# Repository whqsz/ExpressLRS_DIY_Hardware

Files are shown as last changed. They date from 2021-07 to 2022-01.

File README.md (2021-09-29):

# DIY ExpressLRS E19 E28 ESP32 TX And RX
开源固件访问http://github.com/ExpressLRS/ExpressLRS

view elrs view

接收机
----------------------------------------------------------

接收编译固件名[env:DIY_900_RX_ESP8285_SX127x_via_UART]

915M接收板子尺寸15mm×16mm×4.5mm厚

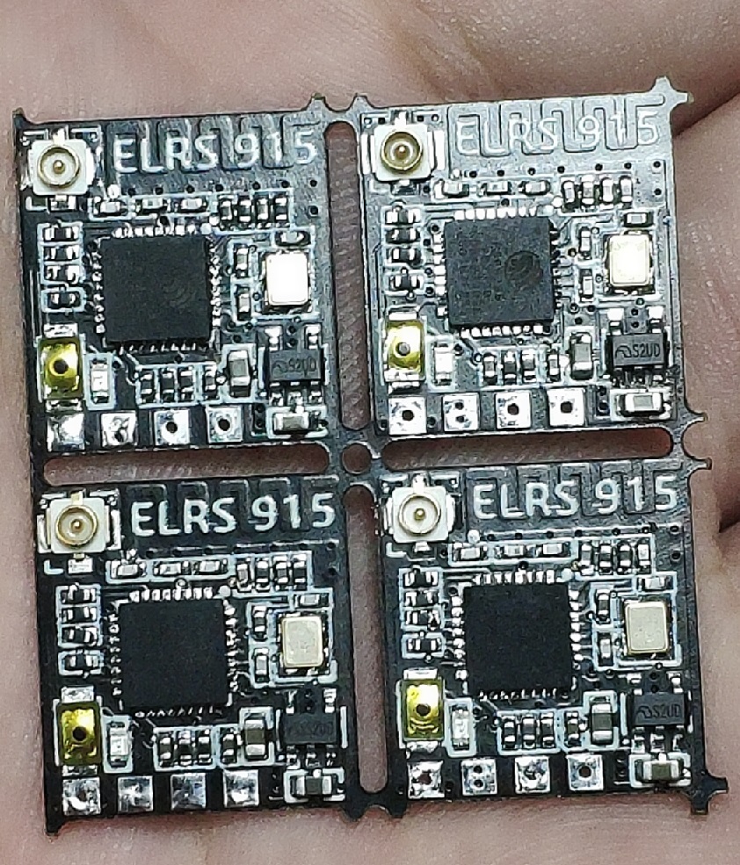
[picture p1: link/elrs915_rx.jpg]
view elrs view


发射机
----------------------------------------------------------

发射编译固件名[env:DIY_900_TX_ESP32_SX127x_E19_via_UART]

发射板targets.h文件定义在65行修改

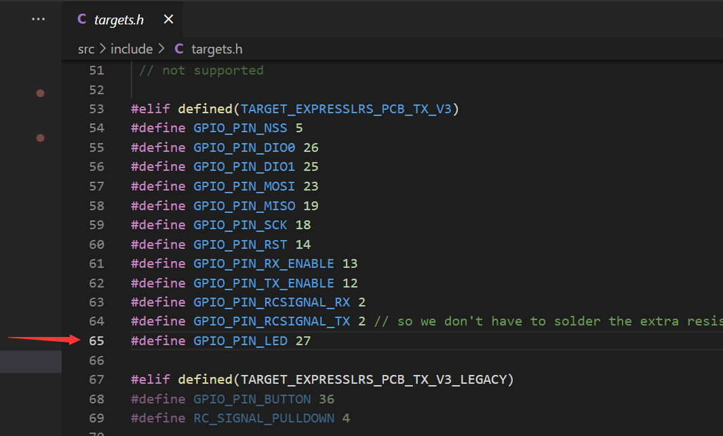
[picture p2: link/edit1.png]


加风扇IO定义

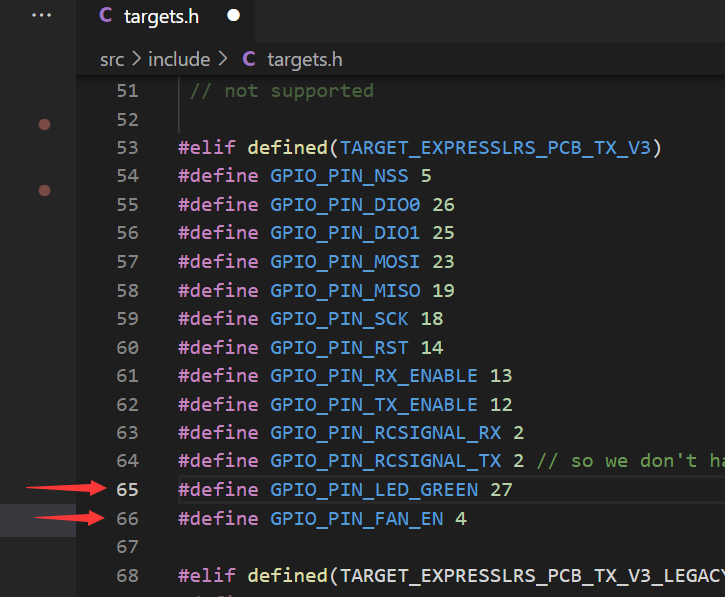
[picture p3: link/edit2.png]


 飞友自制实物
 
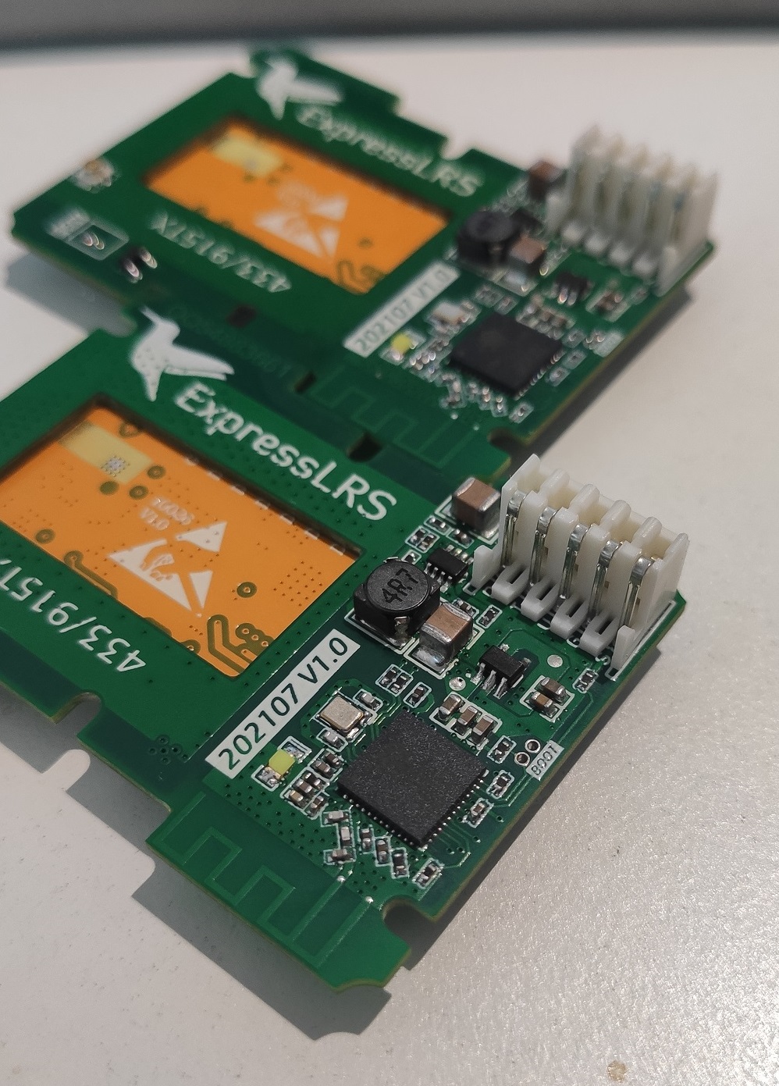
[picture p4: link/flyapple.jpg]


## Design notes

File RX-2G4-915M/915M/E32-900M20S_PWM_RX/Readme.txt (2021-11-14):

基于ExpressLRS 2.0官方源码库引脚定义整理电路图，射频模块选用亿佰特定制型号E32-900M20S
此型号模块内部同样采用SX1276方案，跟常用方案唯一区别就是把天线控制信号调整为由外部单片机端来控制，
所以要在原固件引脚定义下增加两行TXEN跟RXEN定义来驱动射频天线发收状态。
此版本硬件未加入电池电压检测回传，后续要等固件功能加入再做硬件定义。
排针PWM引脚复用功能，同样可以兼容DIY_900_RX CRSF协议固件

PWM1	-- BOOT0下载对GND短接
PWM2	-- TX串口下载 CRSF通讯
PWM3	-- RX串口下载 CRSF通讯
PWM4	--
PWM5	--
PWM6	--

-------------------------------------------------------------------------------------------------------------------------
ExpressLRS 2.0固件添加收发控制定义：
工程文件路径为（ExpressLRS-2.0.0-RC1\src\include\target\DIY_900_RX_PWMP.h）
文本编辑DIY_900_RX_PWMP.h文件，文本结尾追加两行定义：

#define GPIO_PIN_RX_ENABLE      7
#define GPIO_PIN_TX_ENABLE      6

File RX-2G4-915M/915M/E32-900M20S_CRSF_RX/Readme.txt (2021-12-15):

基于ExpressLRS 2.0官方源码库引脚定义整理电路图，射频模块选用亿佰特定制型号E32-900M20S
此型号模块内部同样采用SX1276方案，跟常用方案唯一区别就是把天线控制信号调整为由外部单片机端来控制，
所以要在原固件引脚定义下增加两行TXEN跟RXEN定义来驱动射频天线发收状态。

-------------------------------------------------------------------------------------------------------------------------
ExpressLRS 2.0固件添加收发控制定义：
工程文件路径为（ExpressLRS-2.0.0-RC1\src\include\target\DIY_900_RX_ESP8285_SX127x）
文本编辑DIY_900_RX_ESP8285_SX127x文件

文本结尾追加一行定义：
#define GPIO_PIN_TX_ENABLE      9
#define GPIO_PIN_RX_ENABLE      10

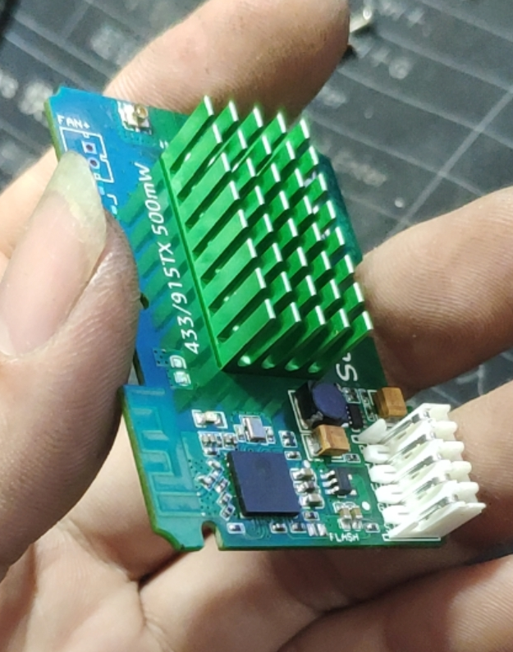
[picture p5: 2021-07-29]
TX/433-915TX/实物.png

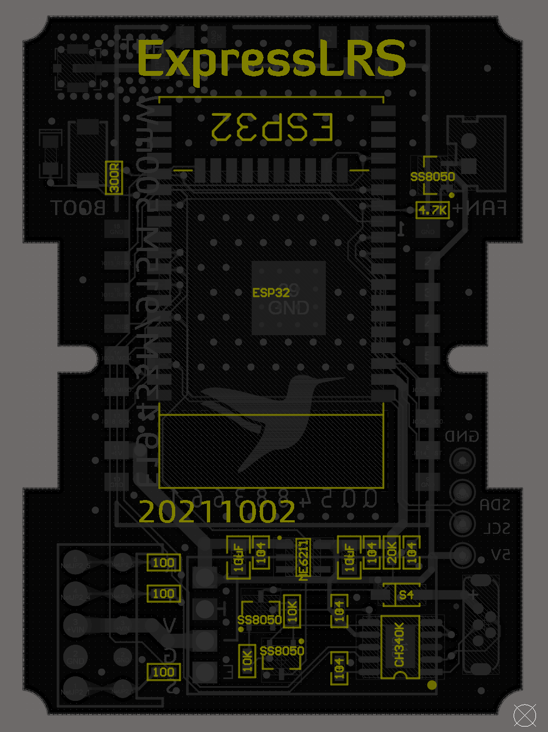
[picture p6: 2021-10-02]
TX/E19_915M_ESP32_FULL_MODULE/焊接点位图.png

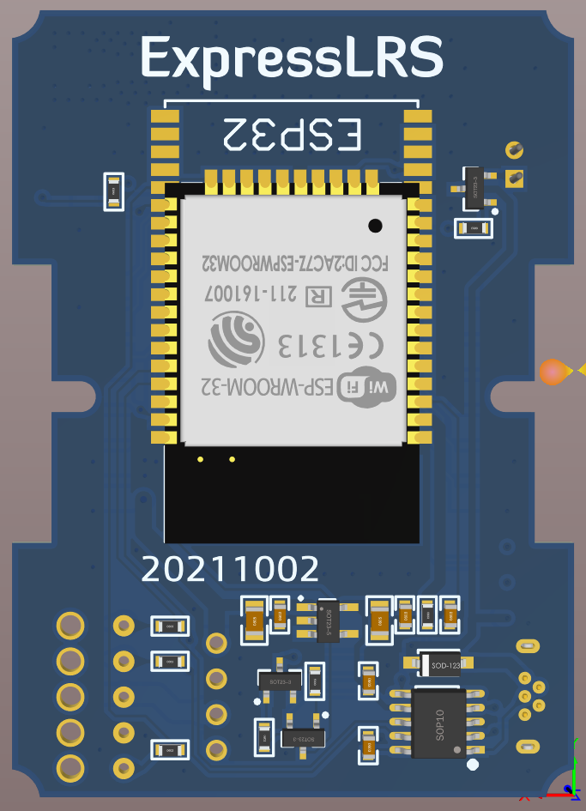
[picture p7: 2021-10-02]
TX/E19_915M_ESP32_FULL_MODULE/3D后.png

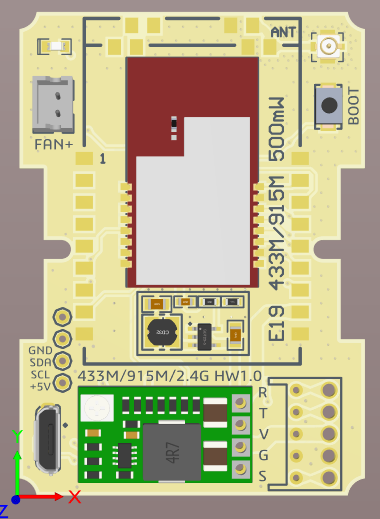
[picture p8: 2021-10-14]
TX/E19_915M_ESP32_2IN1_TX/3D正面.png

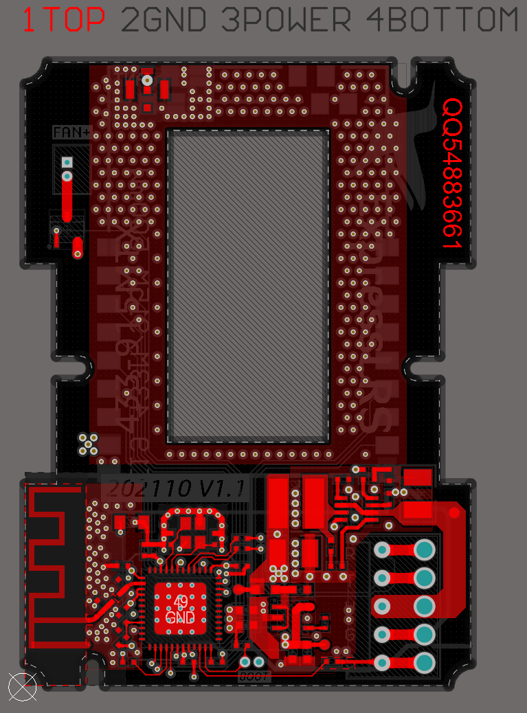
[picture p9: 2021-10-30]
TX/433-915TX/TOP_LAYER.png

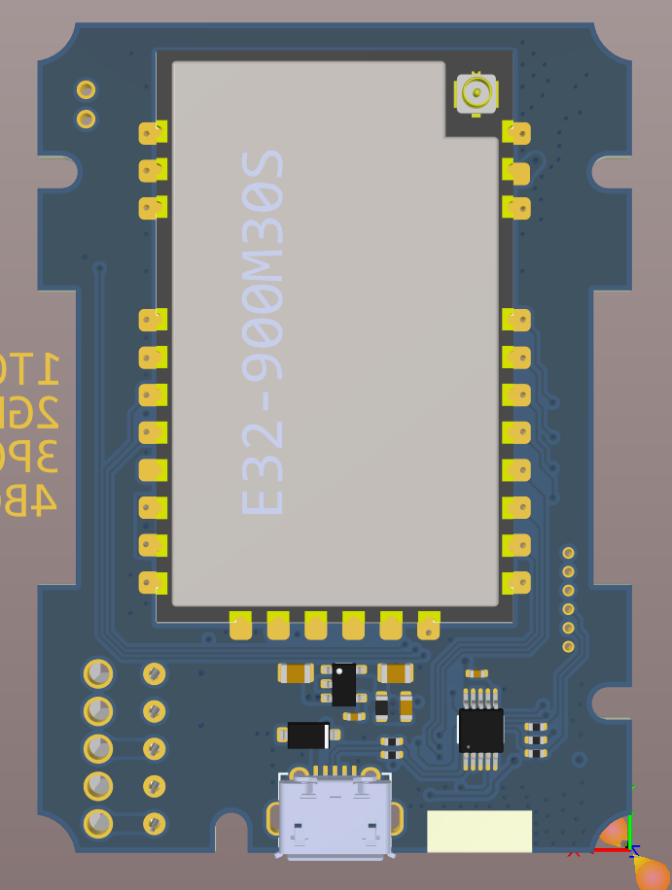
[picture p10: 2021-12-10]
TX/E32_900M30S_TX/3D背面.png

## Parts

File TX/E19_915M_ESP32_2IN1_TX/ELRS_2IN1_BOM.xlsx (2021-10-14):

Comment | Description | Designator | Footprint | LibRef | Quantity
100nF | 无极性贴片电容, Capacitor | C1, C3, C4, C6, C9, C10 | C 0603_L | C, Cap | 6
10uF | 无极性贴片电容, Capacitor | C2, C5, C7, C8 | C 0805_L | C, Cap | 4
S4 | 肖特基二极管 | D1 | SOD123 | SS14 | 1
HDR-1X3 | 3P接插件 | JP1 | IPEX | Header 3 | 1
HDR-1X4 | 4P接插件 | JP2 | J-LINK | Header 4 | 1
HDR-1X2 | 2P接插件 | JP3 | PH2.0-2 | Header 2 | 1
HDR-1X5 | 5P接插件 | JP4 | B2541BW-5P | Header 5 | 1
HDR-1X4 | 4P接插件 | JP5 | MP2315-MODULE-SMT | Header 4 | 1
2.2uH | 小功率贴片电感 | L1 | CD32 | L | 1
RED_LED | 贴片LED | LED1 | LED0805TB | LED-SMD | 1
SS8050 | 高频放大-NPN型 | Q1, Q2, Q3 | SOT23-3L | 8050-SMD | 3
20K | 贴片电阻 | R1 | R 0603_L | R | 1
470R | 贴片电阻 | R2 | R 0603_L | R | 1
100R | 贴片电阻 | R3, R5, R6 | R 0603_L | R | 3
1K | 贴片电阻 | R4 | R 0603_L | R | 1
45K | 贴片电阻 | R7 | R 0603_L | R | 1
10K | 贴片电阻 | R8, R9, R10 | R 0603_L | R | 3
FLASH | 侧按直插6x6轻触开关 | SW1 | KEY-K2 | TSW DIP-6x6_V | 1
E19-433/915M30S | 433/915射频模块 | U1 | E19_2IN1 | LORA-SX1276M | 1
ESP32 | ESP32模块 | U2 | ESP32 | ESP32 | 1
STI3408B_1A | 3.3V降压IC | U3 | SOT23-5L | STI3408B_1A | 1
ME6211 | 3.3V降压压LDO | U4 | SOT23-5M | ME6211 | 1
LORA-E28-2G4M | 2.4G射频模块 | U5 | E28-2G4M2XS | LORA-E28-2G4M | 1
CH340K | USB到TTL芯片 | U6 | CH340K | CH340K | 1
USB-5P | 微型USB母座 | USB1 | USB-micro_C | USB-5P | 1

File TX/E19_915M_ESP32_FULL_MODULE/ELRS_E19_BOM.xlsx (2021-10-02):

Comment | Description | Designator | Footprint | LibRef | Quantity
104 | 无极性贴片电容 | C1, C3, C5, C6, C7 | C 0603_L | C | 5
10uF | 无极性贴片电容 | C2, C4 | C 0805_L | C | 2
S4 | 肖特基二极管 | D1 | SOD123 | SS14 | 1
HDR-1X2 | 2P接插件 | JP1 | PH2.0-2 | Header 2 | 1
HDR-1X5 | 5P接插件 | JP2 | B2541BW-5P | Header 5 | 1
HDR-1X3 | 3P接插件 | JP3 | IPEX | Header 3 | 1
HDR-1X4 | 4P接插件 | JP4 | MP2315-MODULE-SMT | Header 4 | 1
HDR-1X4 | 4P接插件 | JP5 | J-LINK | Header 4 | 1
RED_LED | 贴片LED | LED1 | LED0805TB | LED-SMD | 1
SS8050 | 高频放大-NPN型 | Q1, Q2, Q3 | SOT23-3L | 8050-SMD | 3
470R | 贴片电阻 | R1 | R 0603_L | R | 1
20K | 贴片电阻 | R2 | R 0603_L | R | 1
4.7K | 贴片电阻 | R3 | R 0603_L | R | 1
100 | 贴片电阻 | R4, R5, R6 | R 0603_L | R | 3
10K | 贴片电阻 | R7, R8 | R 0603_L | R | 2
FLASH | 侧按直插6x6轻触开关 | SW1 | KEY-K2 | TSW DIP-6x6_V | 1
ESP32 | 乐鑫ESP32模块 | U1 | ESP32 | ESP32 | 1
ME6211 | 3.3V LDO | U2 | SOT23-5M | ME6211 | 1
E19-433/915M30S | 亿佰特915模块 | U3 | E19_2IN1 | LORA-SX1276M | 1
CH340K | USB转串口芯片 | U4 | CH340K | CH340K | 1
USB-5P | 微型USB母座 | USB1 | USB-micro_C | USB-5P | 1

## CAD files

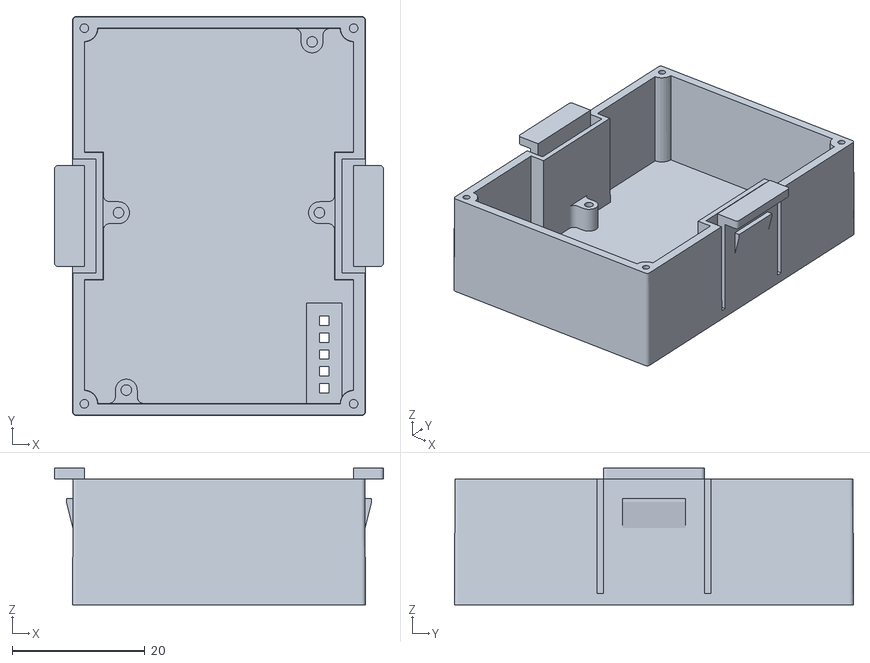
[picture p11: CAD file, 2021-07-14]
TX/433-915TX/STL外壳打印文件/New JR bay for ES24TX_ 1修改.STL
49.6 x 60.1 x 20.6

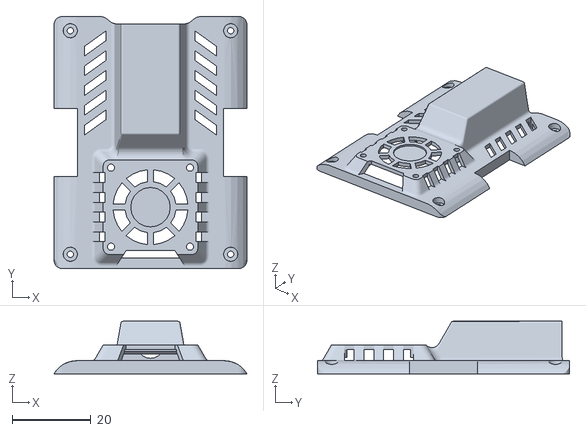
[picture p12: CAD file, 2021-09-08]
TX/E19_915M_ESP32_FULL_MODULE/JR外壳3D/HM_JR__上盖25MM风扇.STL
48.8 x 63.8 x 13.3

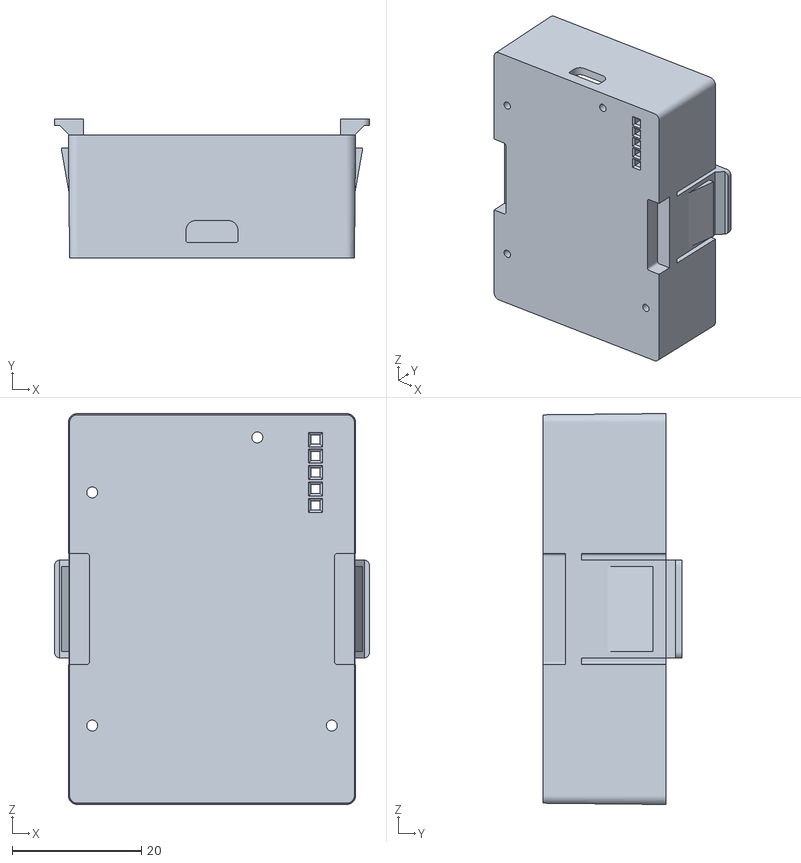
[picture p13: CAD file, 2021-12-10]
TX/E32_900M30S_TX/JR_BOX.STL
48.7 x 21.5 x 60.4

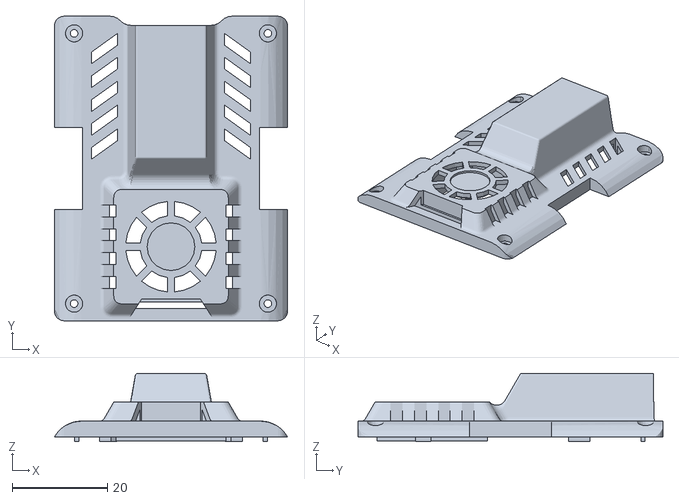
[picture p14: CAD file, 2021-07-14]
TX/433-915TX/STL外壳打印文件/New JR bay for ES24TX_2.stl
48.8 x 63.8 x 14.3

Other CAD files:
TX/E19_915M_ESP32_2IN1_TX/JR外壳3D/HM_JR_ 下盖修改.STL
TX/E19_915M_ESP32_FULL_MODULE/JR外壳3D/HM_JR_ 下盖修改.STL

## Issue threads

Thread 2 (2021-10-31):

433-915TX版本晶振的问题

avanx, 2021-10-31:
ESP32-PICO-D4片内应该是集成了晶振，板上应该不需要再焊接一个晶振了吧
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

whqsz, 2022-02-05:
是的，后面版本已经改正

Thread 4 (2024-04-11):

project TX/E32_900M30S_TX

forhardcore, 2024-04-11:
Congratulations! Can you share the schematic and PCB files to import into EasyEDA, I want to make some changes to install the board in my case. I will be grateful! Thanks!

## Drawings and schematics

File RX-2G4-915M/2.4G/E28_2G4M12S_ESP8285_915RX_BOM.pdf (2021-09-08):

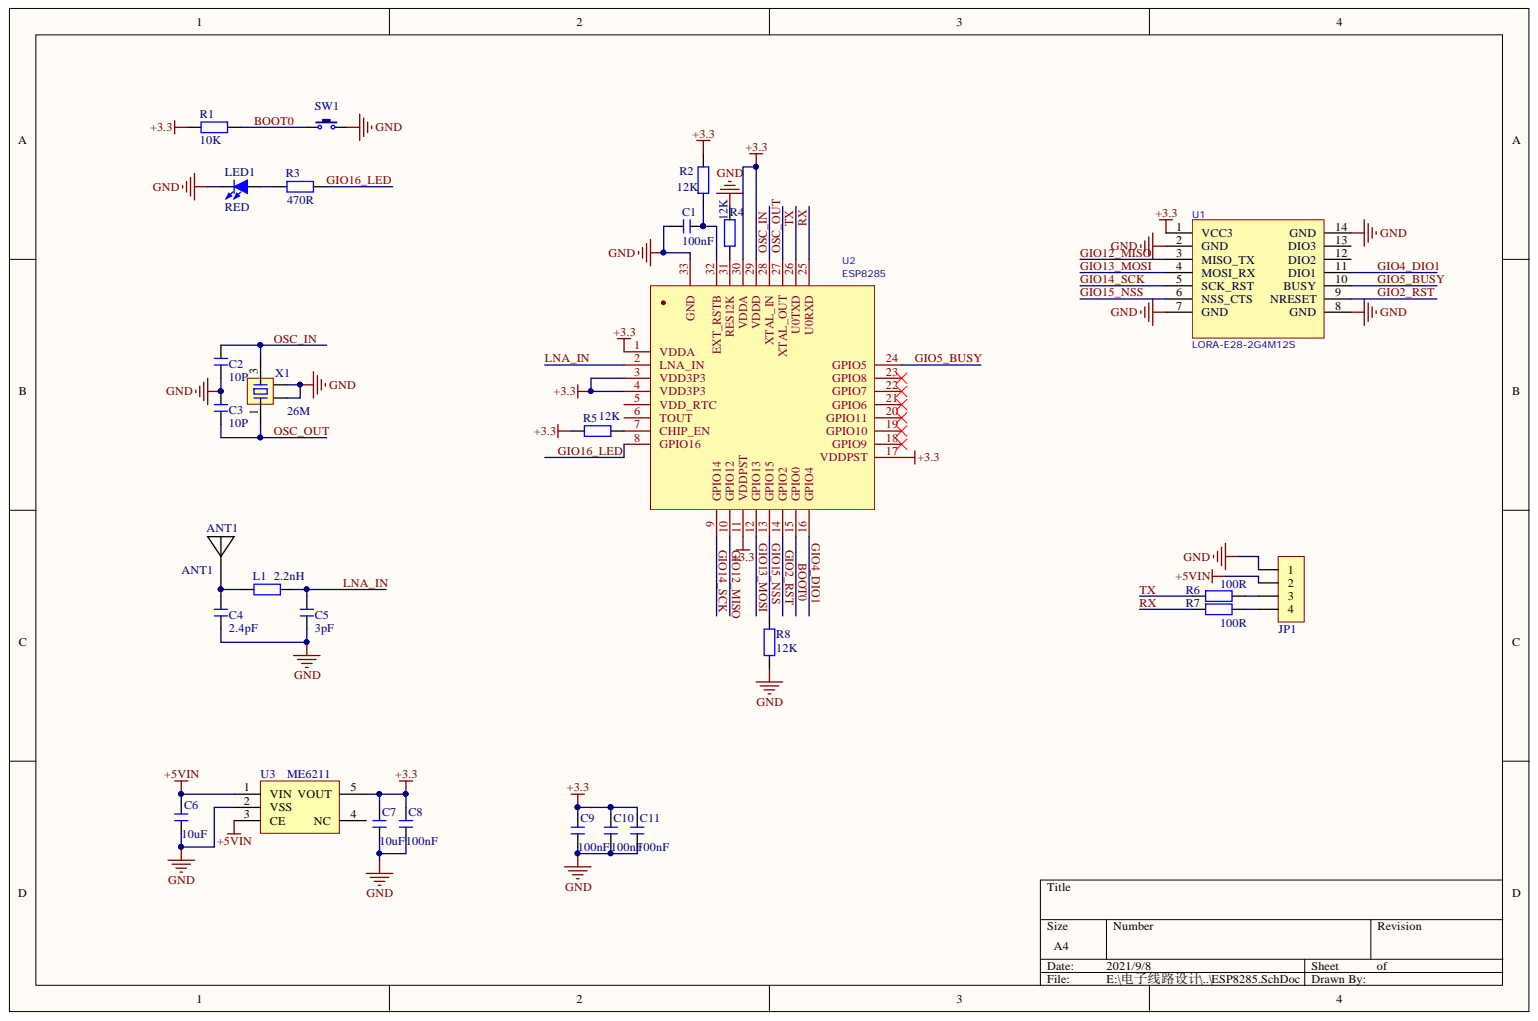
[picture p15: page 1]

VDD3P3 3
VDD3P3 4

OSC_OUT

GIO16_LED

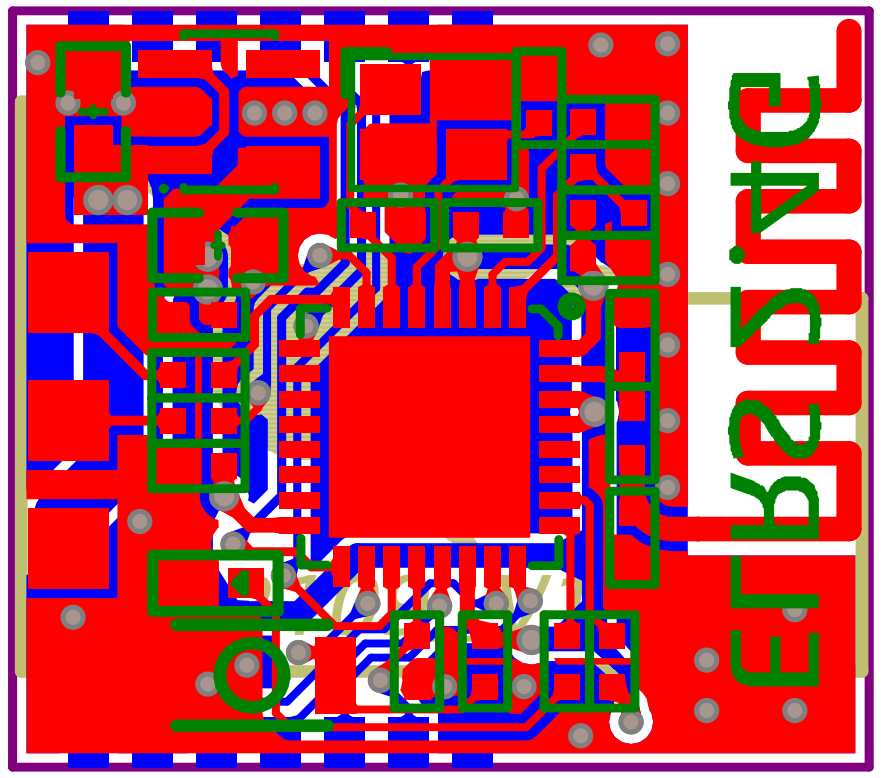
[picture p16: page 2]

Comment | Description | Designator | Footprint | LibRef | Quantity
ANT1 | PCB板载天线 | ANT1 | 2.4_ANT | ANT1 | 1
100nF | 无极性贴片电容 | C1, C8, C9, C10, C11 | C0402S | C | 5
10P | 无极性贴片电容 | C2, C3 | C0402S | C | 2
2.4pF | 无极性贴片电容 | C4 | C0402S | C | 1
3pF | 无极性贴片电容 | C5 | C0402S | C | 1
10uF | 无极性贴片电容 | C6, C7 | C 0603_L | C | 2
HDR-1X4 | 4P接插件 | JP1 | RC4P | Header 4 | 1
2.2nH | 贴片电阻 | L1 | R0402S | R | 1
RED | 贴片LED | LED1 | 0402LED R | LED-SMD | 1
10K | 贴片电阻 | R1 | R0402S | R | 1
12K | 贴片电阻 | R2, R4, R5, R8 | R0402S | R | 4
470R | 贴片电阻 | R3 | R0402S | R | 1
100R | 贴片电阻 | R6, R7 | R0402S | R | 2
FLASH | 侧按直插6x6轻触开 关 | SW1 | SW-SMD_L3.0-W2.0-LS3.5 | TSW DIP-6x6_V | 1
LORA-E28-2G4M12S | | U1 | E28-2G4M12S | LORA-E28-2G4M12S | 1
ESP8285 | | U2 | QFN32 | ESP8285 | 1
ME6211 | | U3 | SOT23-5A | ME6211 | 1
26M | 4脚无源晶振 | X1 | OSC 2025-4P | XTAL-4P | 1

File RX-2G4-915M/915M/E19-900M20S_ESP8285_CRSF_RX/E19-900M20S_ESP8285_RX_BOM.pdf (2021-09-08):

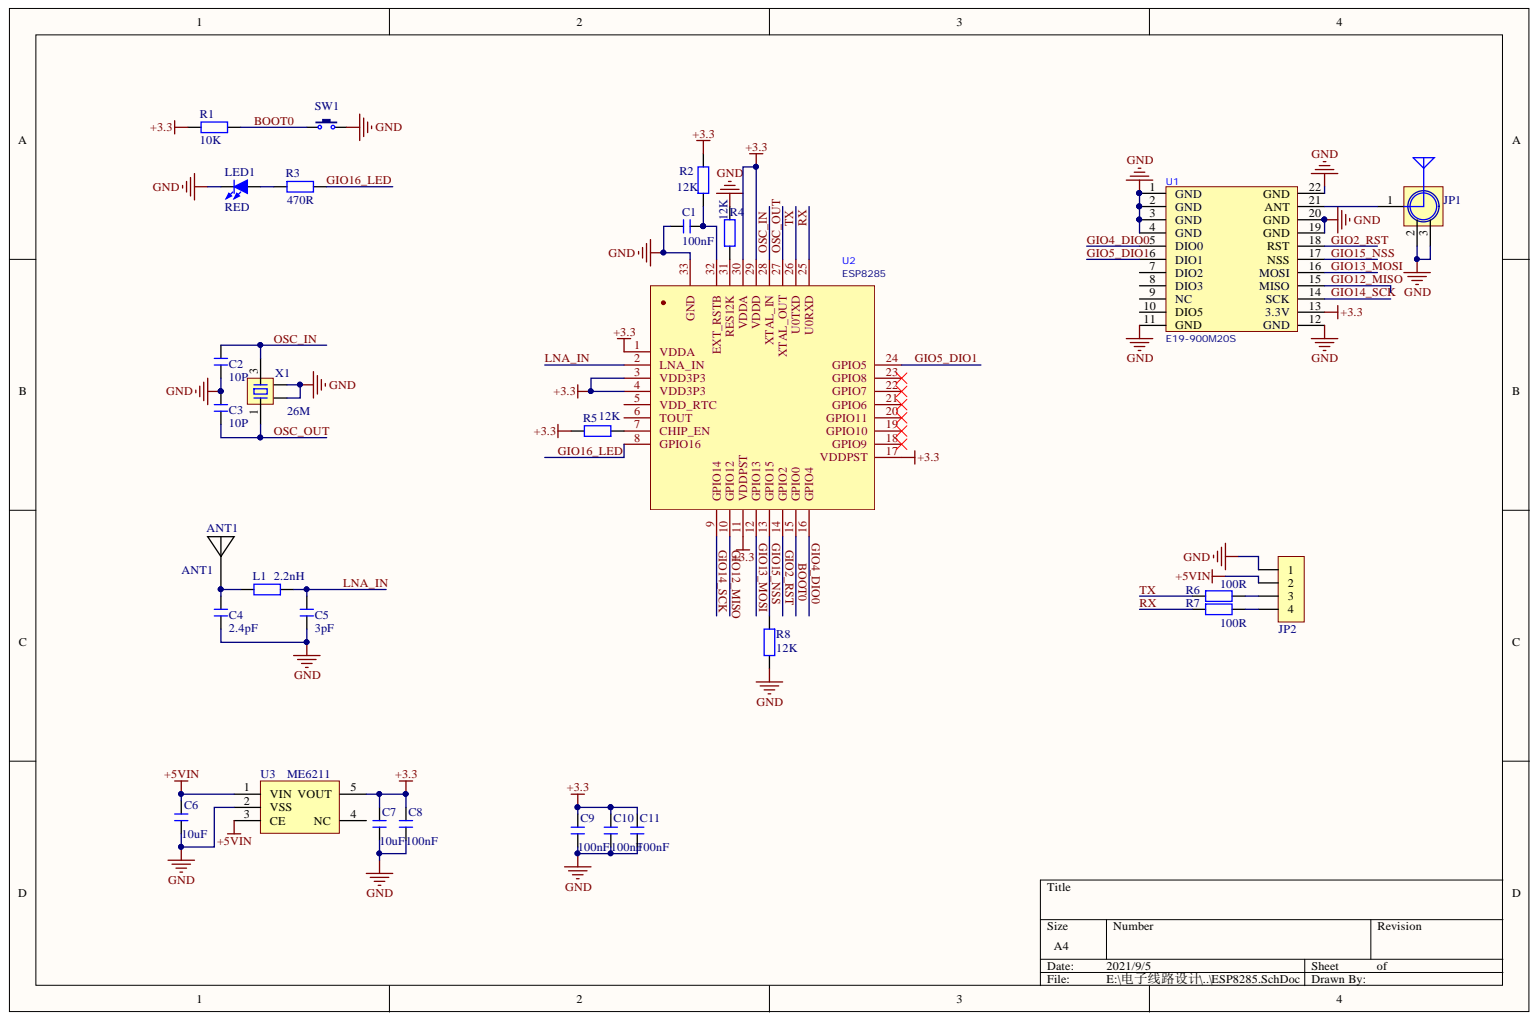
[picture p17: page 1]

VDD3P3 3
VDD3P3 4

OSC_OUT

GIO16_LED

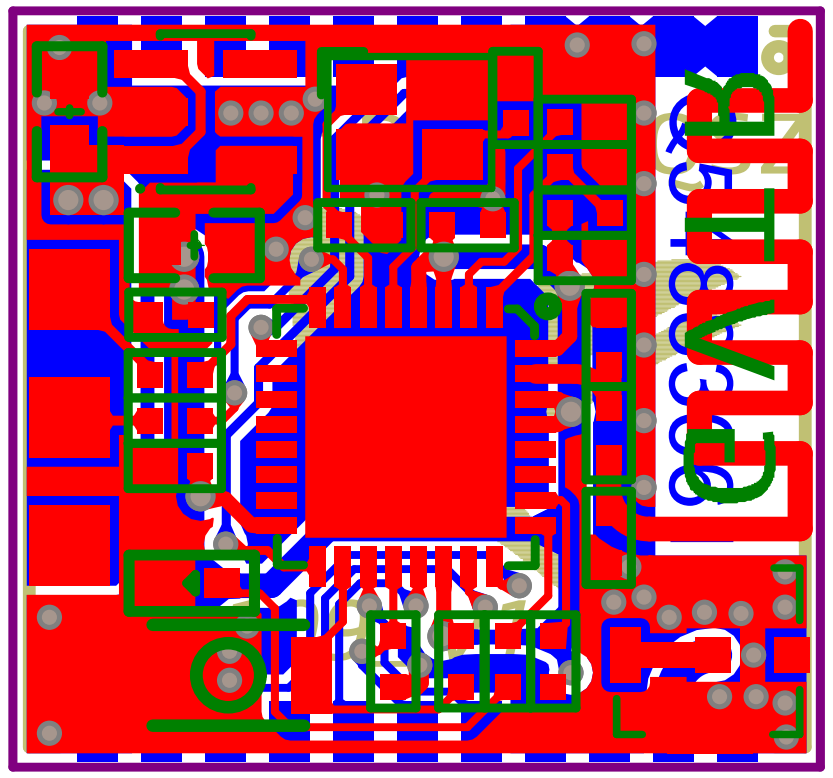
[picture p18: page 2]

Comment | Description | Designator | Footprint | LibRef | Quantity
ANT1 | PCB板载天线 | ANT1 | 2.4_ANT | ANT1 | 1
100nF | 无极性贴片电容 | C1, C8, C9, C10, C11 | C0402S | C | 5
10P | 无极性贴片电容 | C2, C3 | C0402S | C | 2
2.4pF | 无极性贴片电容 | C4 | C0402S | C | 1
3pF | 无极性贴片电容 | C5 | C0402S | C | 1
10uF | 无极性贴片电容 | C6, C7 | C 0603_L | C | 2
915M | SMA-2.4G射频天线接 口 | JP1 | IPEX | SMA | 1
HDR-1X4 | 4P接插件 | JP2 | RC4P | Header 4 | 1
2.2nH | 贴片电阻 | L1 | R0402S | R | 1
RED | 贴片LED | LED1 | 0402LED R | LED-SMD | 1
10K | 贴片电阻 | R1 | R0402S | R | 1
12K | 贴片电阻 | R2, R4, R5, R8 | R0402S | R | 4
470R | 贴片电阻 | R3 | R0402S | R | 1
100R | 贴片电阻 | R6, R7 | R0402S | R | 2
FLASH | 侧按直插6x6轻触开 关 | SW1 | SW-SMD_L3.0-W2.0-LS3.5 | TSW DIP-6x6_V | 1
E19-900M20S | | U1 | EBYTE_LORA_22PIN _15X15 -L | E19-900M20S | 1
ESP8285 | | U2 | QFN32 | ESP8285 | 1
ME6211 | | U3 | SOT23-5A | ME6211 | 1
26M | 4脚无源晶振 | X1 | OSC 2025-4P | XTAL-4P | 1

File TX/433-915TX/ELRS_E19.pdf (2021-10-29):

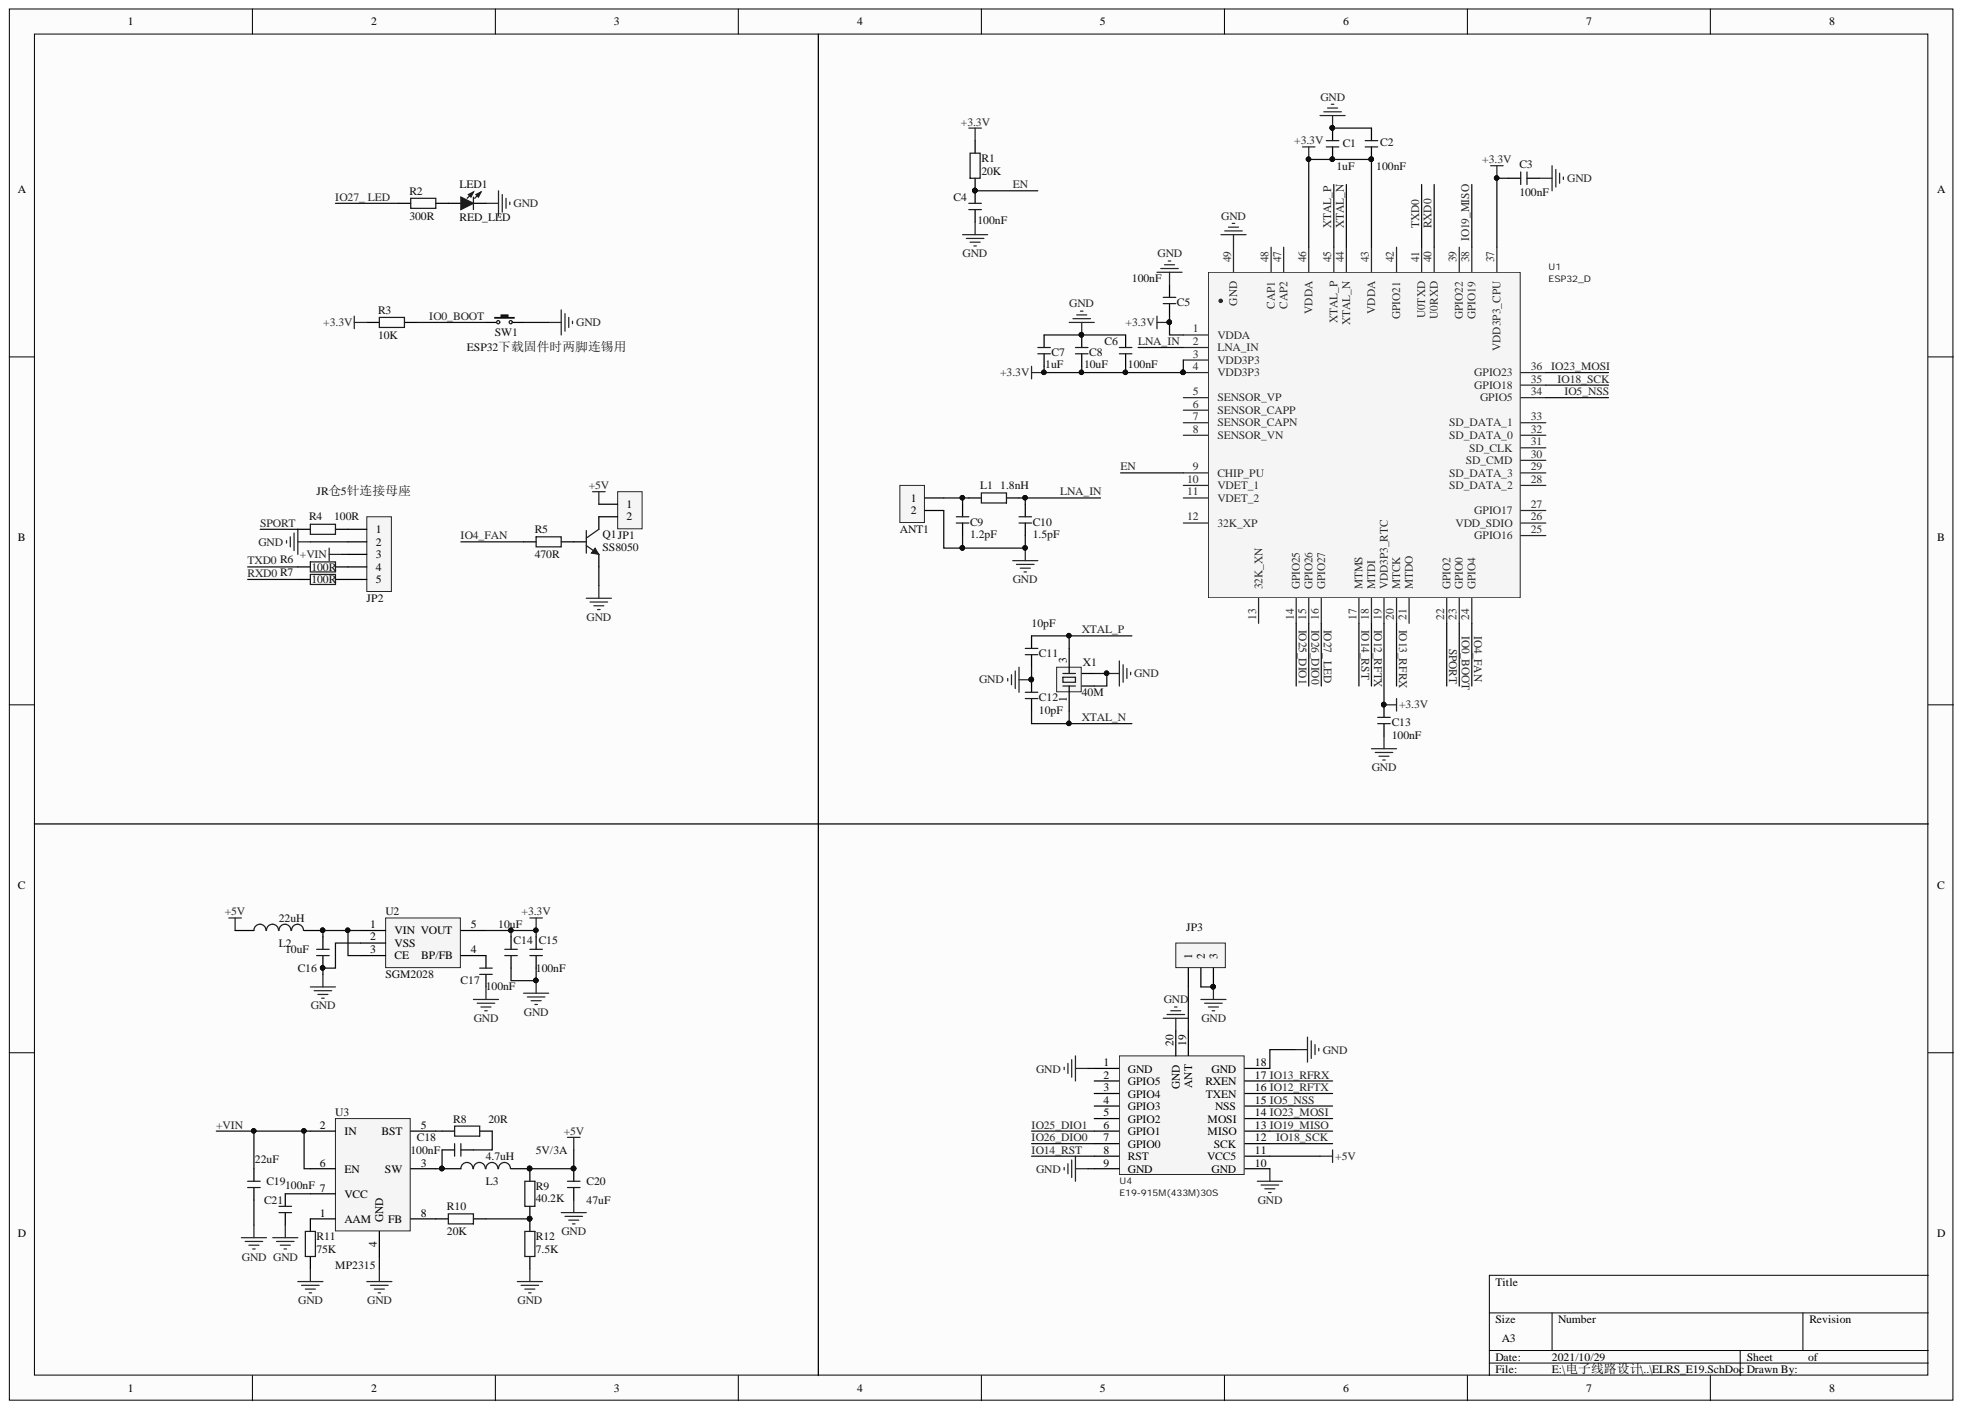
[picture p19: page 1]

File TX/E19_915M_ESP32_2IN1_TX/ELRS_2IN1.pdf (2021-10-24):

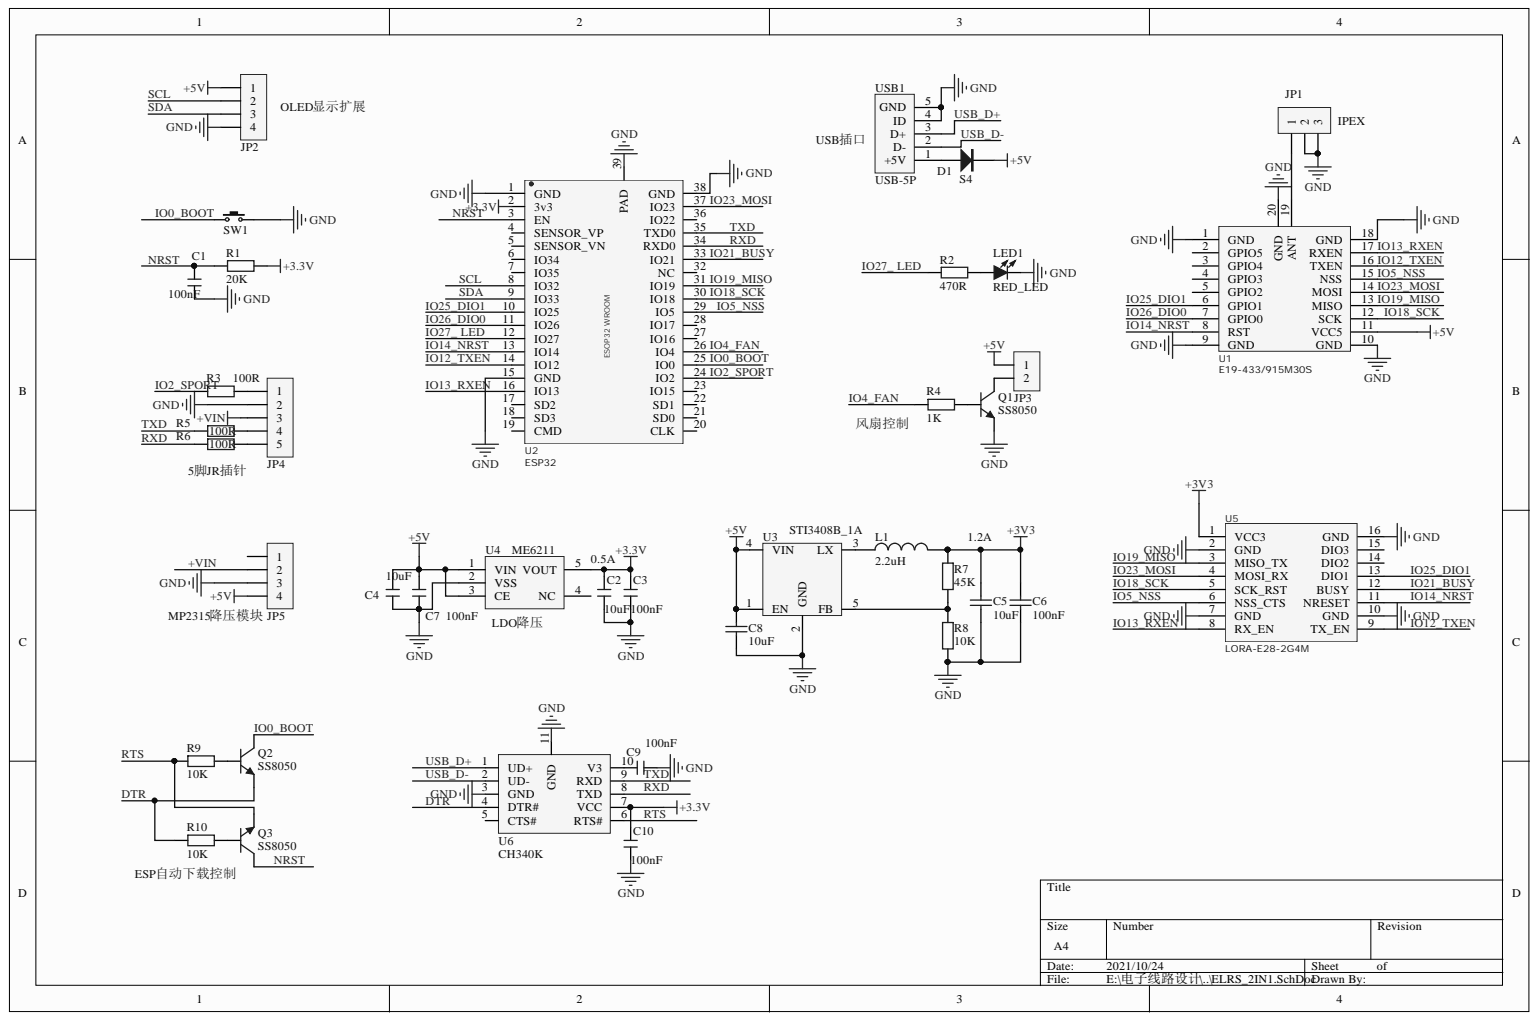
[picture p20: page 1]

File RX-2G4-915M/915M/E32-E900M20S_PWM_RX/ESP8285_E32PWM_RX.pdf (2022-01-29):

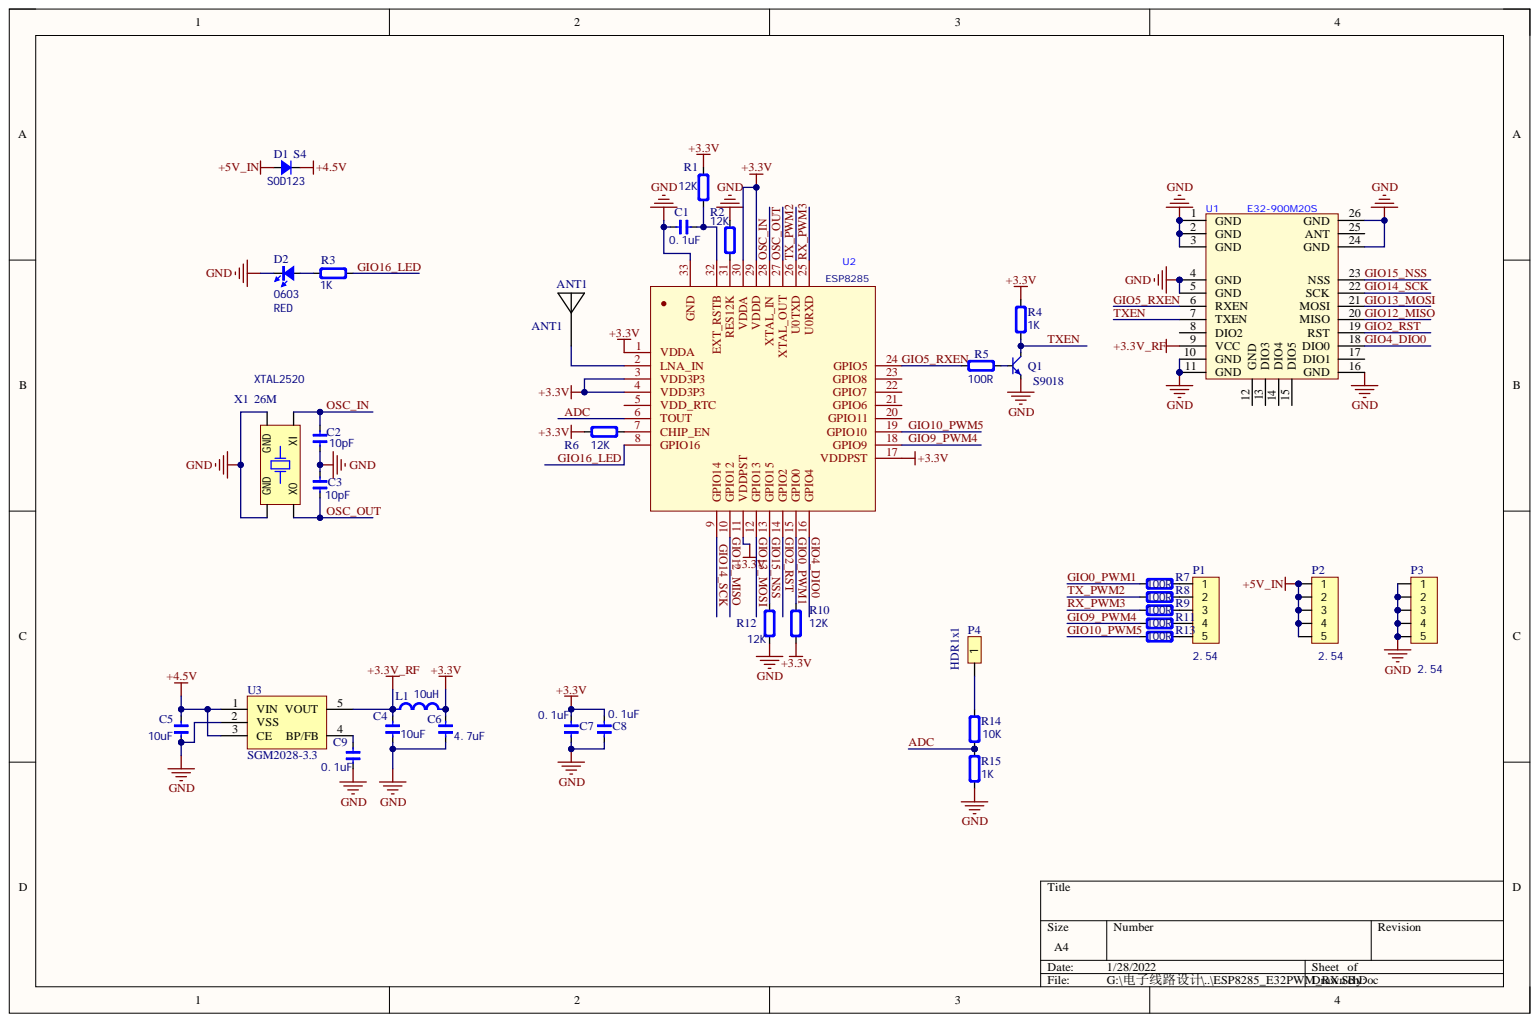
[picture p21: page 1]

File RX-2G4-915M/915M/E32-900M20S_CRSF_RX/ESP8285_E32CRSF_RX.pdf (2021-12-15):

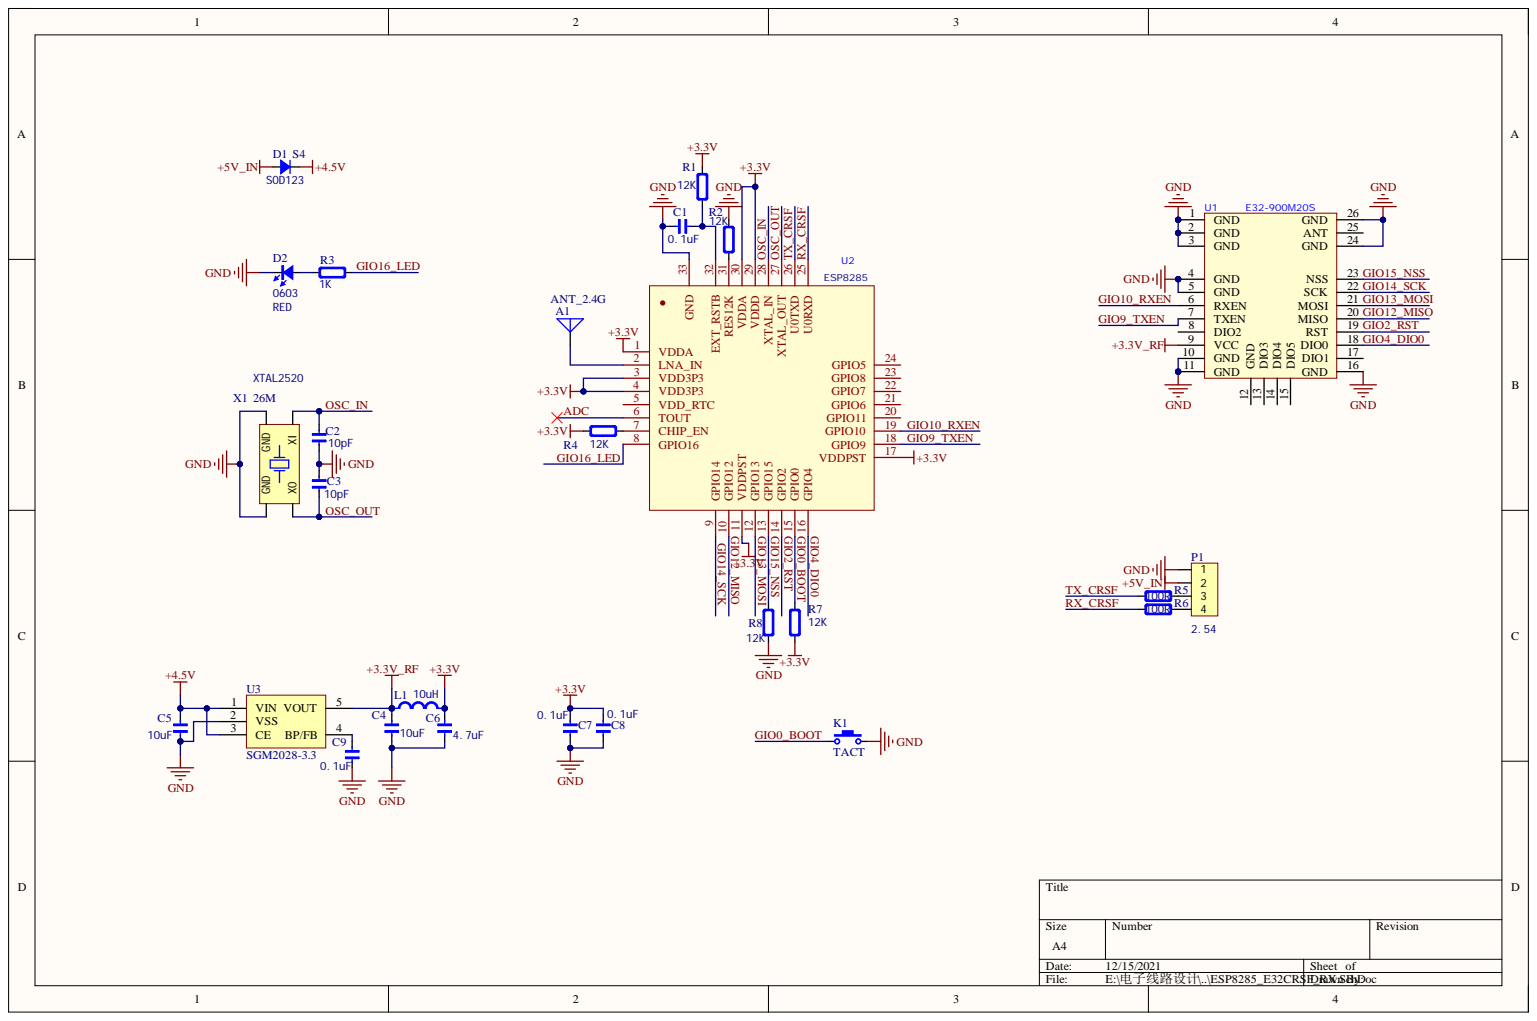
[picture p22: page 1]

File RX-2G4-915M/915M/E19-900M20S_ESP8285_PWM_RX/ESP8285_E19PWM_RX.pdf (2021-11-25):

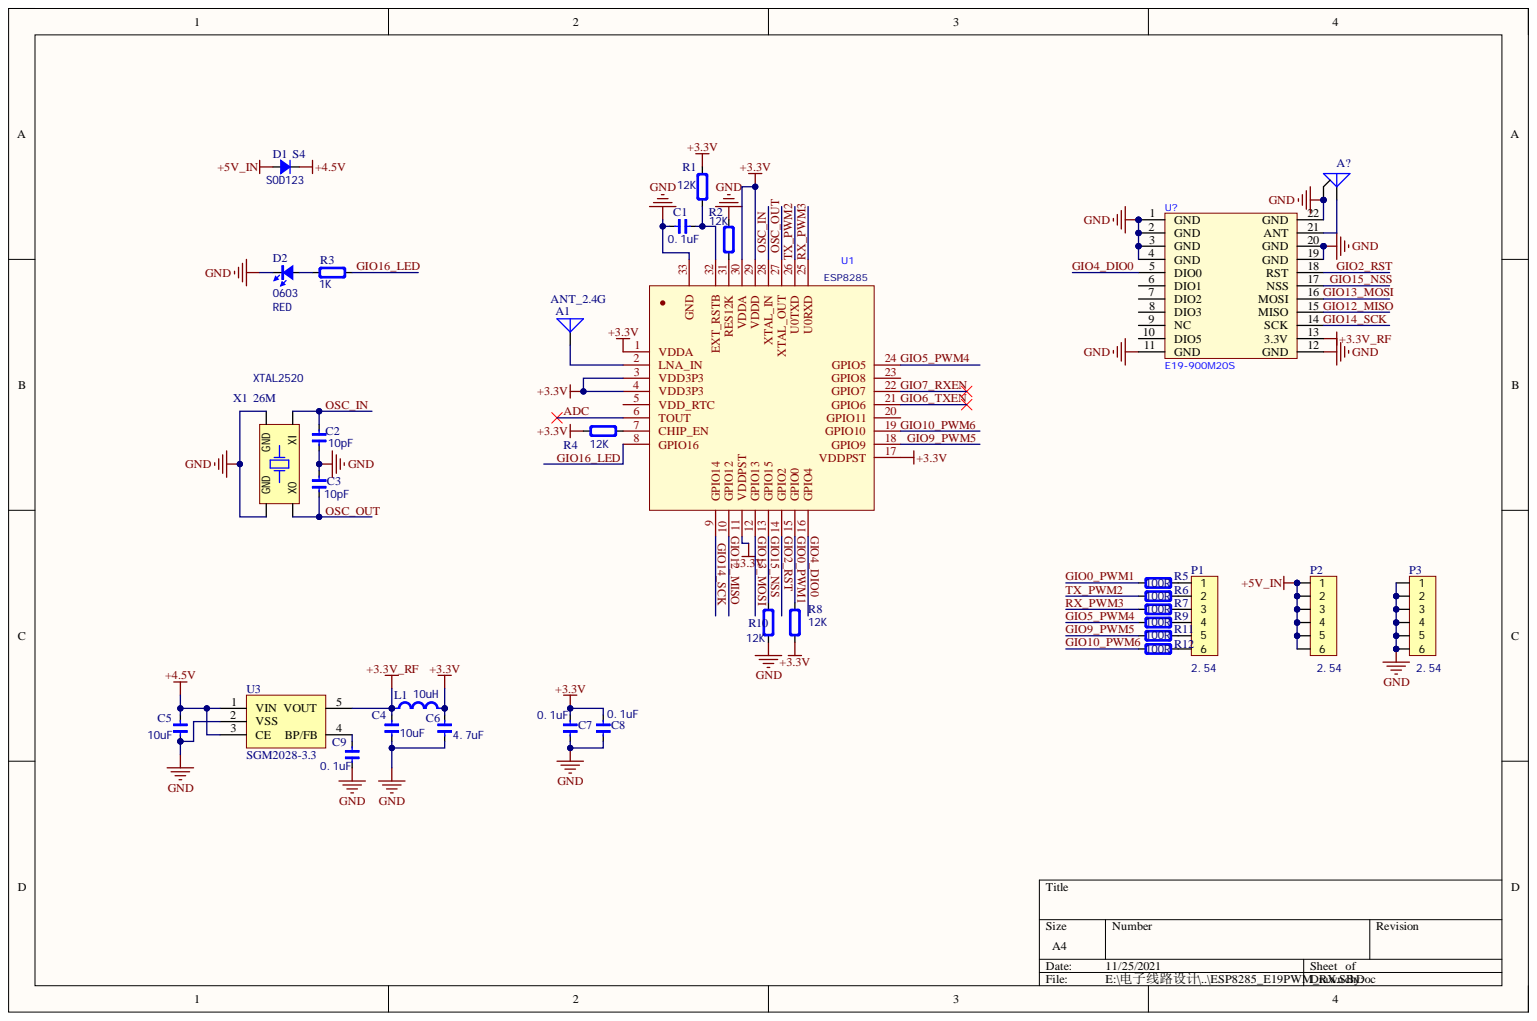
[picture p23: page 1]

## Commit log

2021-07-29 whqsz
    1，散热片位置向上挪动一1mm，风扇不会顶到散热片。
    2，内平面层覆铜割地。
    [BOM.xlsx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]
2021-10-02 whqsz
    add full module
    [ELRS_E19_BOM.xlsx, HM_JR_ 下盖修改.STL, HM_JR__上盖25MM风扇.STL]
